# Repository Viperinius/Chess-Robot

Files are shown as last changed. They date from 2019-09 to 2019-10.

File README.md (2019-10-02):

# Chess-Robot

## Structure Overview
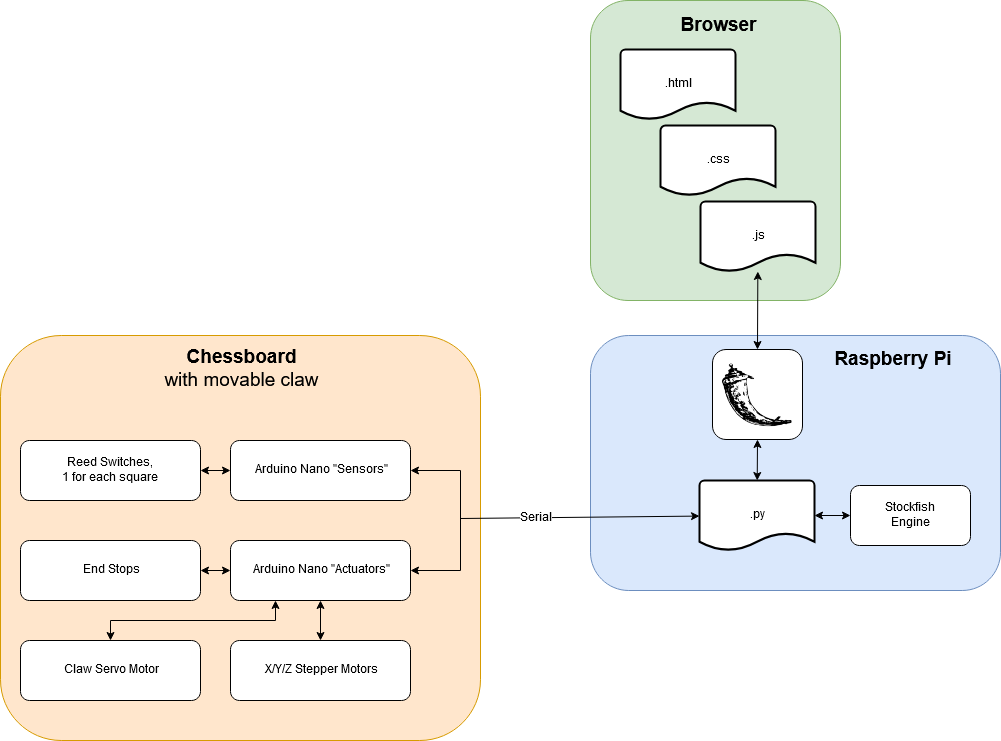
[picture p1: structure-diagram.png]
structOverviewImg


## Frame Design
Currently draft only:
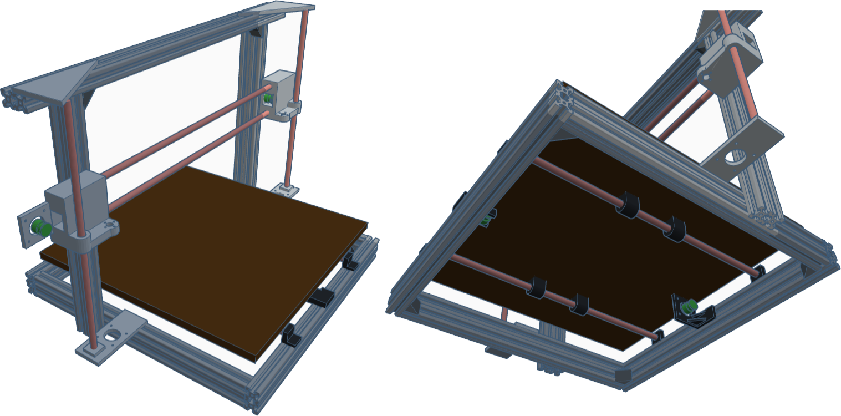
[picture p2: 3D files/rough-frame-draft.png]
frameDraftImg


## Current Schematic and PCB
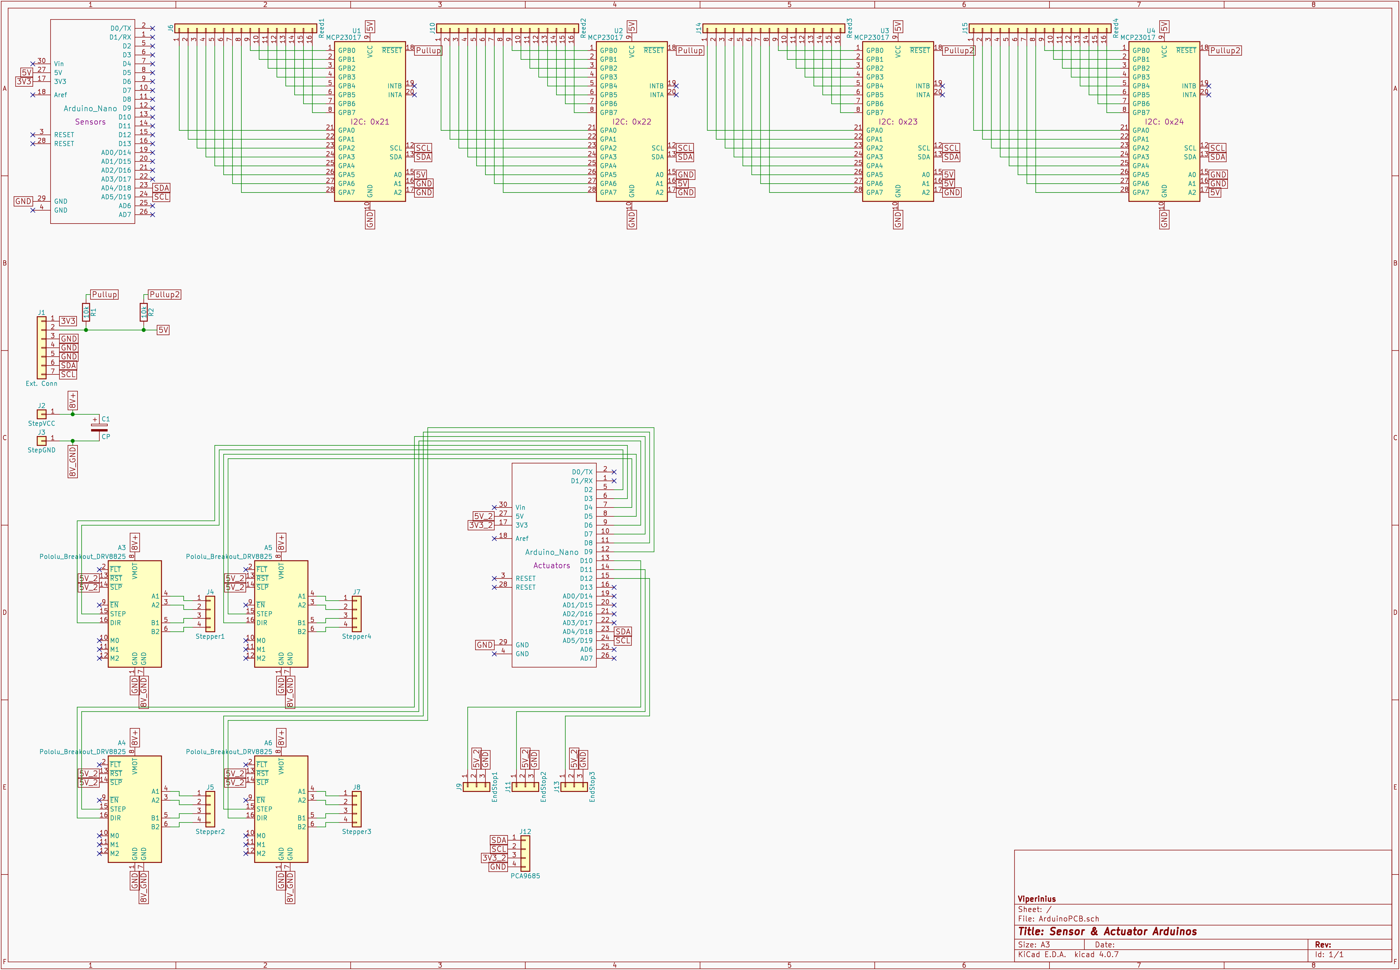
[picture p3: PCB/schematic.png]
schematicImg


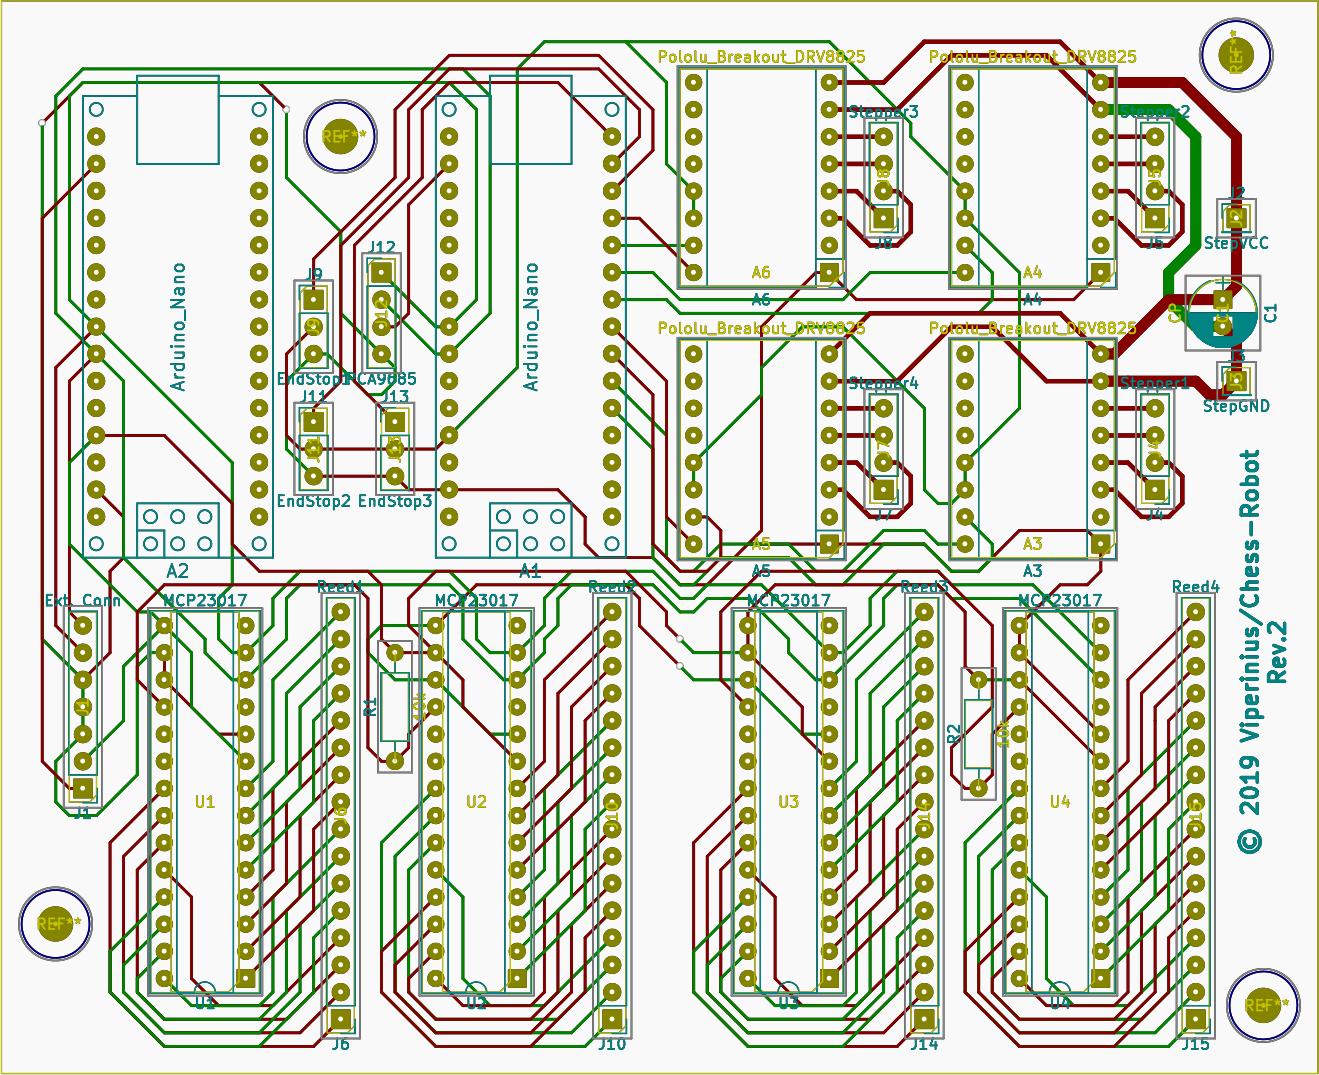
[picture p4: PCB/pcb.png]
pcbImg


## Used libraries / Libraries needed to run
- Used for programming web page, Stockfish & Arduino bridge:
    + [Adafruit MCP23017 Library](https://github.com/adafruit/Adafruit-MCP23017-Arduino-Library)
    + [chess.js](https://github.com/jhlywa/chess.js)
    + [chessboardjs](https://github.com/oakmac/chessboardjs/)
    + [Stockfish](https://github.com/official-stockfish/Stockfish)
    + [stockfish Python package](https://github.com/zhelyabuzhsky/stockfish)
- Used for schematic / PCB layout (KiCad):
    + [arduino_nano](https://github.com/kiwichrish/kicad_ArduinoNano)

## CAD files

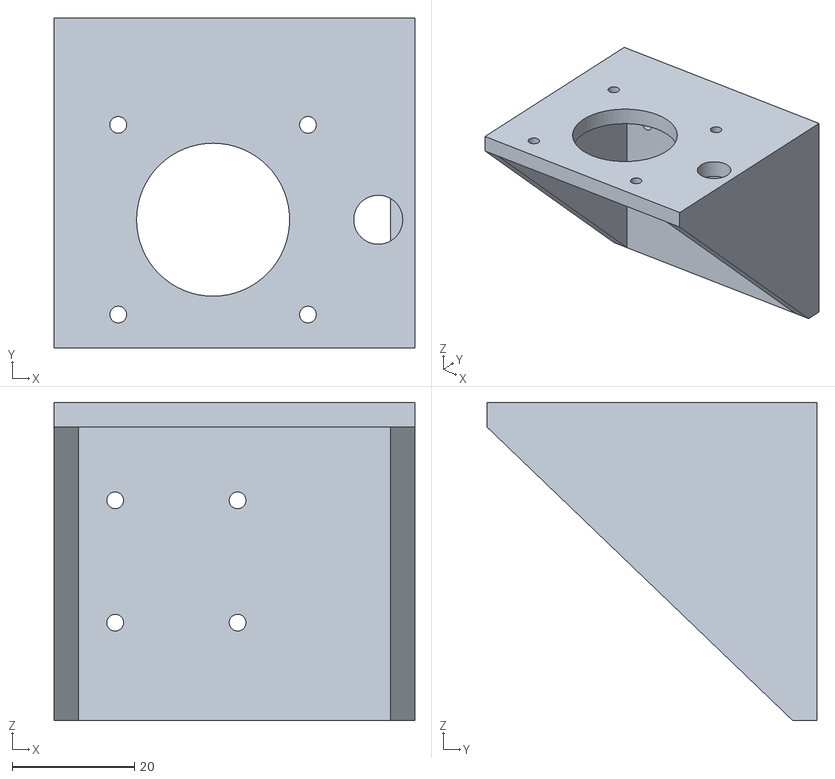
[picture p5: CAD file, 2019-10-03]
3D files/frame-bottom/z-stepper-holder-right.stl
59.0 x 54.0 x 52.0

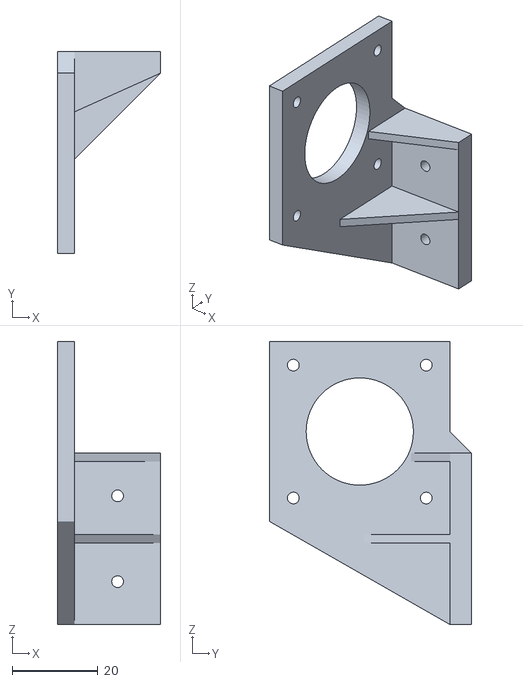
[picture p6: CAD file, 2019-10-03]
3D files/frame-bottom/y-stepper-holder.stl
24.0 x 47.0 x 66.0

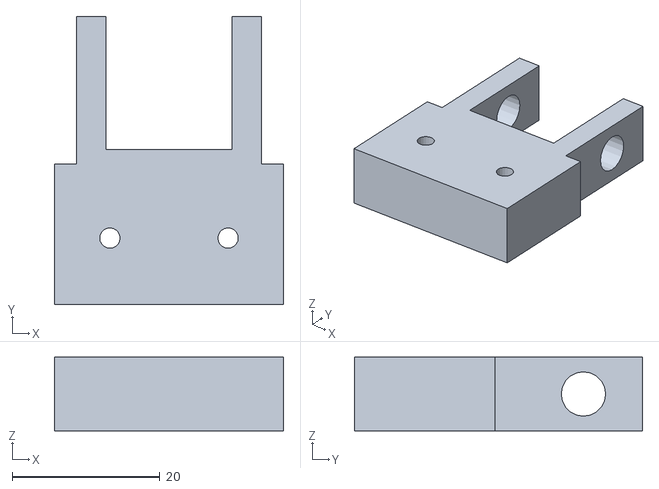
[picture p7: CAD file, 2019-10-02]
3D files/frame-bottom/belt-guide-holder.stl
31.0 x 39.0 x 10.0

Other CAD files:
3D files/frame-bottom/z-stepper-holder-left.stl

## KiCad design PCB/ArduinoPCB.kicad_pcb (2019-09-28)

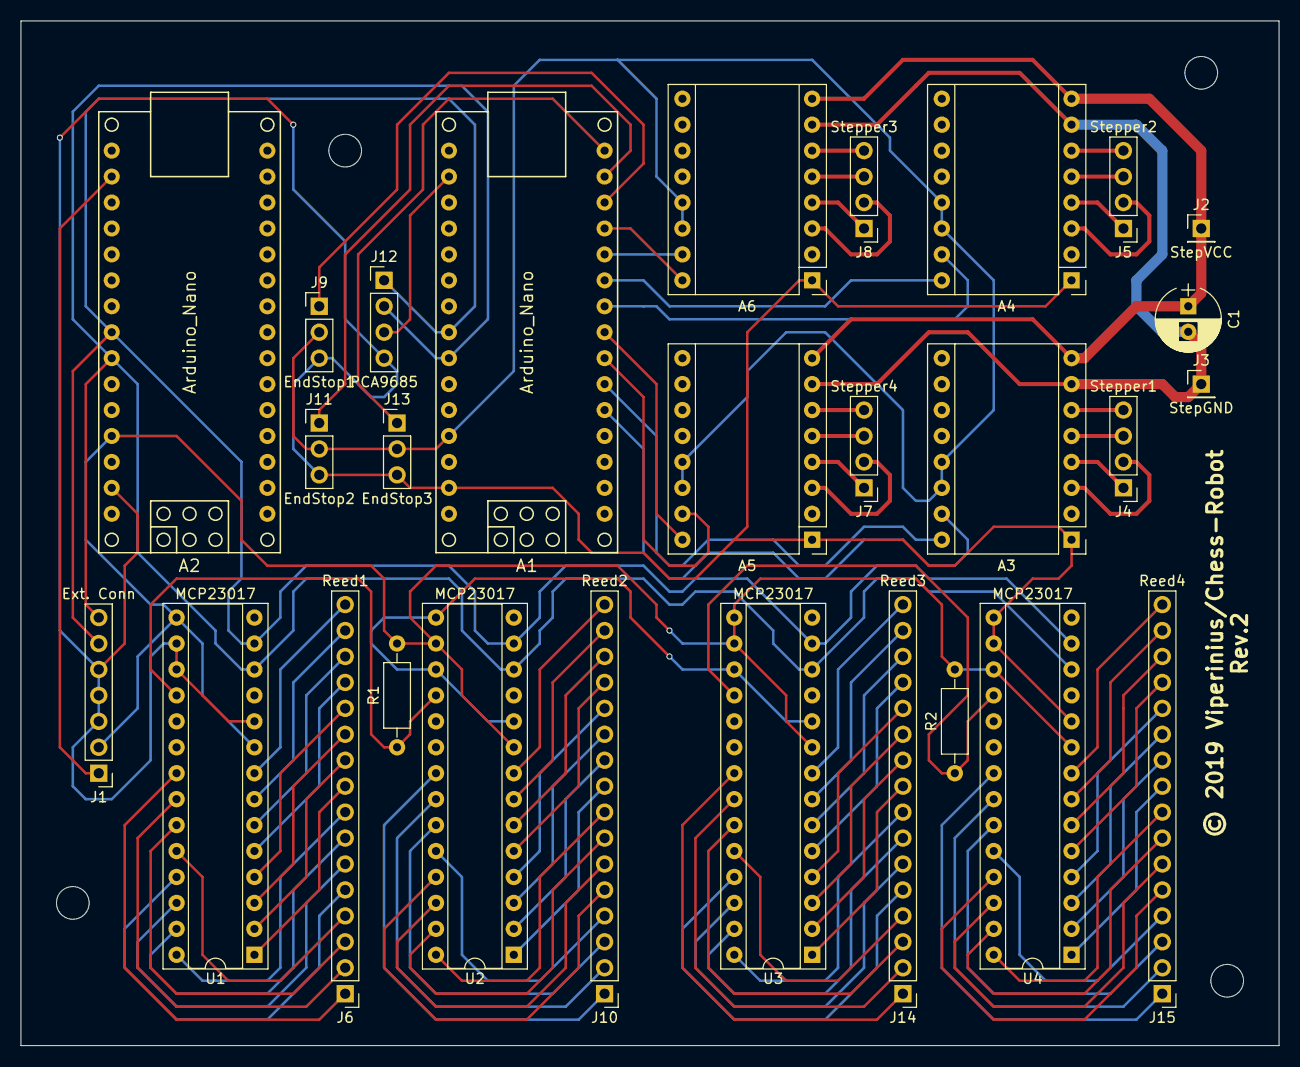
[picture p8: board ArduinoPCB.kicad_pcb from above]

Board: 2 copper layers, 123.2 x 100.3 mm, 28 parts (0 on the bottom side), 102 nets.

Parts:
A1, A2: Arduino_Nano; arduino_nano
A3, A4, A5, A6: Pololu_Breakout_DRV8825; Pololu_Breakout-16_15.2x20.3mm
C1: CP; CP_Radial_D6.3mm_P2.50mm
J1: Ext. Conn; Pin_Header_Straight_1x07_Pitch2.54mm
J2: StepVCC; Pin_Header_Straight_1x01_Pitch2.54mm
J3: StepGND; Pin_Header_Straight_1x01_Pitch2.54mm
J4: Stepper1; Pin_Header_Straight_1x04_Pitch2.54mm
J5: Stepper2; Pin_Header_Straight_1x04_Pitch2.54mm
J6: Reed1; Pin_Header_Straight_1x16_Pitch2.54mm
J7: Stepper4; Pin_Header_Straight_1x04_Pitch2.54mm
J8: Stepper3; Pin_Header_Straight_1x04_Pitch2.54mm
J9: EndStop1; Pin_Header_Straight_1x03_Pitch2.54mm
J10: Reed2; Pin_Header_Straight_1x16_Pitch2.54mm
J11: EndStop2; Pin_Header_Straight_1x03_Pitch2.54mm
J12: PCA9685; Pin_Header_Straight_1x04_Pitch2.54mm
J13: EndStop3; Pin_Header_Straight_1x03_Pitch2.54mm
J14: Reed3; Pin_Header_Straight_1x16_Pitch2.54mm
J15: Reed4; Pin_Header_Straight_1x16_Pitch2.54mm
R1, R2: 10k; R_Axial_DIN0207_L6.3mm_D2.5mm_P10.16mm_Horizontal
U1, U2, U3, U4: MCP23017; DIP-28_W7.62mm_Socket

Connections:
3V3: A2.17, J1.1
3V3_2: A1.17, J12.3
5V: A2.27, J1.2, R1.2, R2.2, U1.9, U1.15, U2.9, U2.16, U3.9, U3.15, U3.16, U4.9, U4.17
5V_2: A1.27, A3.13, A3.14, A4.13, A4.14, A5.13, A5.14, A6.13, A6.14, J9.2, J11.2, J13.2
8V+: A3.8, A4.8, A5.8, A6.8, C1.1, J2.1
8V_GND: A3.7, A4.7, A5.7, A6.7, C1.2, J3.1
GND: A1.29, A2.29, A3.1, A4.1, A5.1, A6.1, J1.3, J1.4, J1.5, J9.3, J11.3, J12.4, J13.3, U1.10, U1.16, U1.17, U2.10, U2.15, U2.17, U3.10, U3.17, U4.10, U4.15, U4.16
unnamed: A1.5, A3.15
unnamed: A1.6, A3.16
unnamed: A1.7, A5.15
unnamed: A1.8, A5.16
unnamed: A1.9, A4.15
unnamed: A1.10, A4.16
unnamed: A1.11, A6.15
unnamed: A1.12, A6.16
unnamed: A1.13, J9.1
unnamed: A1.14, J11.1
unnamed: A1.15, J13.1
unnamed: A3.3, J4.2
unnamed: A3.4, J4.1
unnamed: A3.5, J4.3
unnamed: A3.6, J4.4
unnamed: A4.3, J5.2
unnamed: A4.4, J5.1
unnamed: A4.5, J5.3
unnamed: A4.6, J5.4
unnamed: A5.3, J7.2
unnamed: A5.4, J7.1
unnamed: A5.5, J7.3
unnamed: A5.6, J7.4
unnamed: A6.3, J8.2
unnamed: A6.4, J8.1
unnamed: A6.5, J8.3
unnamed: A6.6, J8.4
unnamed: J6.1, U1.21
unnamed: J6.2, U1.22
unnamed: J6.3, U1.23
unnamed: J6.4, U1.24
unnamed: J6.5, U1.25
unnamed: J6.6, U1.26
unnamed: J6.7, U1.27
unnamed: J6.8, U1.28
unnamed: J6.9, U1.1
unnamed: J6.10, U1.2
unnamed: J6.11, U1.3
unnamed: J6.12, U1.4
unnamed: J6.13, U1.5
unnamed: J6.14, U1.6
unnamed: J6.15, U1.7
unnamed: J6.16, U1.8
unnamed: J10.1, U2.21
unnamed: J10.2, U2.22
unnamed: J10.3, U2.23
unnamed: J10.4, U2.24
unnamed: J10.5, U2.25
unnamed: J10.6, U2.26
unnamed: J10.7, U2.27
unnamed: J10.8, U2.28
unnamed: J10.9, U2.1
unnamed: J10.10, U2.2
unnamed: J10.11, U2.3
unnamed: J10.12, U2.4
unnamed: J10.13, U2.5
unnamed: J10.14, U2.6
unnamed: J10.15, U2.7
unnamed: J10.16, U2.8
unnamed: J14.1, U3.21
unnamed: J14.2, U3.22
unnamed: J14.3, U3.23
unnamed: J14.4, U3.24
unnamed: J14.5, U3.25
unnamed: J14.6, U3.26
unnamed: J14.7, U3.27
unnamed: J14.8, U3.28
unnamed: J14.9, U3.1
unnamed: J14.10, U3.2
unnamed: J14.11, U3.3
unnamed: J14.12, U3.4
unnamed: J14.13, U3.5
unnamed: J14.14, U3.6
unnamed: J14.15, U3.7
unnamed: J14.16, U3.8
unnamed: J15.1, U4.21
unnamed: J15.2, U4.22
unnamed: J15.3, U4.23
unnamed: J15.4, U4.24
unnamed: J15.5, U4.25
unnamed: J15.6, U4.26
unnamed: J15.7, U4.27
unnamed: J15.8, U4.28
unnamed: J15.9, U4.1
unnamed: J15.10, U4.2
unnamed: J15.11, U4.3
unnamed: J15.12, U4.4
unnamed: J15.13, U4.5
unnamed: J15.14, U4.6
unnamed: J15.15, U4.7
unnamed: J15.16, U4.8
Pullup: R1.1, U1.18, U2.18
Pullup2: R2.1, U3.18, U4.18
SCL: A1.24, A2.24, J1.7, J12.2, U1.12, U2.12, U3.12, U4.12
SDA: A1.23, A2.23, J1.6, J12.1, U1.13, U2.13, U3.13, U4.13

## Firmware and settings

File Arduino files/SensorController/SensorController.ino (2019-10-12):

//==============================================================================
/// @file SensorController.ino
///
/// @brief Implements reed switch reading and move recognition
///
/// @version 1.2
///
/// @author Viperinius
///
/// @date 11.10.2019
//==============================================================================


/* Board:
    x  x  x  x  x  x  x  x    8    |            MCP78   Pins 8-15
    x  x  x  x  x  x  x  x    7    | black      MCP78   Pins 0-7
    x  x  x  x  x  x  x  x    6                 MCP56   Pins 8-15
    x  x  x  x  x  x  x  x    5                 MCP56   Pins 0-7
    x  x  x  x  x  x  x  x    4                 MCP34   Pins 8-15
    x  x  x  x  x  x  x  x    3                 MCP34   Pins 0-7
    x  x  x  x  x  x  x  x    2    | white      MCP12   Pins 8-15
    x  x  x  x  x  x  x  x    1    |            MCP12   Pins 0-7
    a  b  c  d  e  f  g  h                              Pin number increased from left/a to right/h
*/




//------------------------------------------------------------------------------
//                                    Includes
//------------------------------------------------------------------------------

#include <Wire.h>
#include <Adafruit_MCP23017.h>



//------------------------------------------------------------------------------
//                                    Defines
//------------------------------------------------------------------------------
#define DEBUG 1                                 ///< enables or disables certain code for debugging


#define BAUD_RATE 9600                          ///< set the baud raute used to communicate
#define SLEEP_MS 1500                           ///< set how much delay is in between a loop cycle
#define SLEEP_MS_NEW_GAME 90000                 ///< set how much time a player has between requesting a new game and the actual game start
#define REQUEST_POS 10                          ///< message code for a current positions request
#define REQUEST_NEW_GAME 20                     ///< message code for a new game requested
#define MODE_BOARD 1                            ///< code for play mode board only
#define MODE_WEB 2                              ///< code for play mode web

#define REQ_POS_MSG "<SEND_CURR_POS>"           ///< message to expect to recognise a current positions request
#define REQ_NEW_GAME_MSG "<RESET_GAME>"         ///< message to expect to recognise a new game request
#define COMM_READY_MSG "<SENSORS_COMM_READY>"   ///< message to send that communication is ready
#define MODE_MSG_BOARD "<MODE_BOARD>"           ///< message to expect to set play mode to board only
#define MODE_MSG_WEB "<MODE_WEB>"               ///< message to expect to set play mode to web

//------------------------------------------------------------------------------
//                                    Variables
//------------------------------------------------------------------------------

// I/O extenders, each connected to two rows of the board
Adafruit_MCP23017 mcpRow12;        ///< I/O extender for first and second row
Adafruit_MCP23017 mcpRow34;        ///< I/O extender for third and fourth row
Adafruit_MCP23017 mcpRow56;        ///< I/O extender for fifth and sixth row
Adafruit_MCP23017 mcpRow78;        ///< I/O extender for seventh and eighth row

// keep starting positions at hand for easy copying
/// backup of the starting positions
const int iStartPos[8][8] = {
    { 1,1,1,1,1,1,1,1 },
    { 1,1,1,1,1,1,1,1 },
    { 0,0,0,0,0,0,0,0 },
    { 0,0,0,0,0,0,0,0 },
    { 0,0,0,0,0,0,0,0 },
    { 0,0,0,0,0,0,0,0 },
    { 1,1,1,1,1,1,1,1 },
    { 1,1,1,1,1,1,1,1 }
};

// arrays to save read positions
int iPrevPos[8][8];     ///< array to store the previous positions
int iCurrPos[8][8];     ///< array to store the current positions

// status if / what serial message received
int iSerialMsg;         ///< contains the message read from serial

// contains detected move with board columns as numbers instead of letters
int iMove;              ///< contains unformatted detected move

// status if comparePositions has detected a move
bool bMoveDetected;     ///< indicates if comparePostions detected a move

// "play mode", either board only (MODE_BOARD) or on web page (MODE_WEB)
uint8_t uiMode;         ///< contains current play mode

//------------------------------------------------------------------------------
//                                    Functions
//------------------------------------------------------------------------------

//==============================================================================
/// @brief Resets the position arrays
///
/// @details
/// Fill the board position arrays with initial values
//==============================================================================
void resetBoardArr() {
    for (int i = 0; i < 8; i++)
    {
        for (int j = 0; j < 8; j++)
        {
            iCurrPos[i][j] = iStartPos[i][j];
            iPrevPos[i][j] = iStartPos[i][j];
        }
    }
}

//==============================================================================
/// @brief Copy current position array to previous position array
///
/// @details
/// Copies all current positions from their array to the previous one.
//==============================================================================
void copyCurrToPrevPos() {
    for (int i = 0; i < 8; i++)
    {
        for (int j = 0; j < 8; j++)
        {
            iPrevPos[i][j] = iCurrPos[i][j];
        }
    }
}

//==============================================================================
/// @brief Generate unformatted move
///
/// @details
/// Generates the variable containing the unformatted move (move with numbers only)
///
/// @param [in] iSrcI    origin row
/// @param [in] iSrcJ    origin column
/// @param [in] iDestI    destination row
/// @param [in] iDestJ    destination column
///
/// @return The unformatted move as int
//==============================================================================
int generateMoveVar(int iSrcI, int iSrcJ, int iDestI, int iDestJ) {
    //returns move with columns as numbers instead of letters
    return iSrcJ * 1000 + iSrcI * 100 + iDestJ * 10 + iDestI;
}

//==============================================================================
/// @brief Check if move happened
///
/// @details
/// Compares position arrays to check if a piece changed position
///
/// @return -1 if no move detected, unformatted move otherwise
//==============================================================================
int comparePositions() {
    int iSrcI = -1;
    int iSrcJ = -1;
    int iDestI = -1;
    int iDestJ = -1;

    for (int i = 0; i < 8; i++)
    {
        for (int j = 0; j < 8; j++)
        {
            if (iCurrPos[i][j] != iPrevPos[i][j]) {
                if (iCurrPos[i][j] == 1) {
                    //piece appeared

                    iDestI = i;
                    iDestJ = j;
                }
                else if (iCurrPos[i][j] == 0) {
                    //piece disappeared

                    iSrcI = i;
                    iSrcJ = j;
                }
            }
        }
    }

    //return the move if all parts valid, else -1 (no actual move seen)
    if (iSrcI >= 0 && iSrcJ >= 0 && iDestI >= 0 && iDestJ >= 0) {
        bMoveDetected = true;
        return generateMoveVar(iSrcI + 1, iSrcJ + 1, iDestI + 1, iDestJ + 1);
    }
    bMoveDetected = false;
    return -1;
}

//==============================================================================
/// @brief Initialise the MCP23017
///
/// @details
/// Initialises the four port extenders
//==============================================================================
void initMCP() {
    mcpRow12.begin(1);    //I2C: 0x21
    mcpRow34.begin(2);    //I2C: 0x22
    mcpRow56.begin(3);    //I2C: 0x23
    mcpRow78.begin(4);    //I2C: 0x24

    for (int i = 0; i < 16; i++)
    {
        mcpRow12.pinMode(i, INPUT);
        mcpRow34.pinMode(i, INPUT);
        mcpRow56.pinMode(i, INPUT);
        mcpRow78.pinMode(i, INPUT);

        mcpRow12.pullUp(i, HIGH);
        mcpRow34.pullUp(i, HIGH);
        mcpRow56.pullUp(i, HIGH);
        mcpRow78.pullUp(i, HIGH);
    }
}

//==============================================================================
/// @brief Read all reed switches
///
/// @details
/// Reads all inputs of the I/O extenders and fills position arrays
//==============================================================================
void readSensors() {
    int iTemp = 0;
    for (int i = 0; i < 8; i++)
    {
        for (int j = 0; j < 8; j++)
        {
            switch (i)
            {
            case 0:
                iTemp = mcpRow12.digitalRead(j);
                break;
            case 1:
                iTemp = mcpRow12.digitalRead(j + 8);
                break;
            case 2:
                iTemp = mcpRow34.digitalRead(j);
                break;
            case 3:
                iTemp = mcpRow34.digitalRead(j + 8);
                break;
            case 4:
                iTemp = mcpRow56.digitalRead(j);
                break;
            case 5:
                iTemp = mcpRow56.digitalRead(j + 8);
                break;
            case 6:
                iTemp = mcpRow78.digitalRead(j);
                break;
            case 7:
                iTemp = mcpRow78.digitalRead(j + 8);
                break;
            default:
                break;
            }

            // invert actual value because of pullup in mcp / reed switches gnd
            if (iTemp == 1)
            {
                iCurrPos[i][j] = 0;
            }
            else
            {
                iCurrPos[i][j] = 1;
            }
        }
    }    
}

//==============================================================================
/// @brief Read serial
///
/// @details
/// Checks if new serial message available and reads it
///
/// @return -1 if no or incompatible message received, otherwise message codes
//==============================================================================
int readSerial() {
    char cRead;
    String sContent = "";

    if (!Serial.available()) {
        return -1;
    }
    while (Serial.available()) {
        cRead = Serial.read();
        sContent.concat(cRead);
    }
    
    if (sContent == REQ_POS_MSG) {
        return REQUEST_POS;
    }
    else if (sContent == REQ_NEW_GAME_MSG) {
        return REQUEST_NEW_GAME;
    }
    else if (sContent == MODE_MSG_BOARD) {
        return MODE_BOARD;
    }
    else if (sContent == MODE_MSG_WEB) {
        return MODE_WEB;
    }
    else {
        return -1;
    }
}


//------------------------------------------------------------------------------
//                                    Main Functions
//------------------------------------------------------------------------------

//==============================================================================
/// @brief Prepare loop
///
/// @details
/// Initialises needed things
//==============================================================================
void setup() {
    Serial.begin(BAUD_RATE);
    pinMode(LED_BUILTIN, OUTPUT);
    Serial.println(COMM_READY_MSG);

    initMCP();

    resetBoardArr();

    iSerialMsg = 0;
    bMoveDetected = false;
    //set default mode to board only
    uiMode = MODE_BOARD;

#ifdef DEBUG
    Serial.println("SETUP DONE");
#endif // DEBUG

}

//==============================================================================
/// @brief Main loop
///
/// @details
/// Main loop
//==============================================================================
void loop() {
    //check if server sent a request
    iSerialMsg = readSerial();
    if (iSerialMsg > 0) {
        //valid message received
        if (iSerialMsg == REQUEST_POS) {
            iMove = comparePositions();

            if (bMoveDetected) {
                //send latest move
                Serial.println(iMove);
            }
        }
        else if (iSerialMsg == REQUEST_NEW_GAME) {
            resetBoardArr();

            //pause loop to allow players to reposition the pieces back
            delay(SLEEP_MS_NEW_GAME);
        }
        else if (iSerialMsg == MODE_BOARD || iSerialMsg == MODE_WEB) {
            //change mode to received value
            uiMode = iSerialMsg;
        }
    }
    else
    {
        copyCurrToPrevPos();

        readSensors();

        // testing stuff
        Serial.println("-----------");
        //print curr array
        for (int i = 0; i < 8; i++)
        {
            for (int j = 0; j < 8; j++)
            {
                Serial.print(iCurrPos[i][j]);
                Serial.print(" ");
                if (j == 7) {
                    Serial.print("\r\n");
                }
            }
        }
        digitalWrite(LED_BUILTIN, iCurrPos[4][7]);

        // end testing stuff

        if (uiMode == MODE_BOARD) {
            iMove = comparePositions();

            if (bMoveDetected) {
                //send latest move
                Serial.println(iMove);
            }
        }


        delay(SLEEP_MS);
    }

}

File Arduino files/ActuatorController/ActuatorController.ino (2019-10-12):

//==============================================================================
/// @file ActuatorController.ino
///
/// @brief Implements movement control
///
/// @version 1.1
///
/// @author Viperinius
///
/// @date 11.10.2019
//==============================================================================


//------------------------------------------------------------------------------
//                                    Includes
//------------------------------------------------------------------------------

#include <avr/interrupt.h>


//------------------------------------------------------------------------------
//                                    Defines
//------------------------------------------------------------------------------

#define BAUD_RATE 9600                          ///< set the baud raute used to communicate
#define SLEEP_MS 500                            ///< set how much delay is in between loop cycles
#define COMM_READY_MSG "<SENSORS_COMM_READY>"   ///< message to send that communication is ready

#define PIN_END_STOP_1 10                       ///< pin of the x end stop
#define PIN_END_STOP_2 11                       ///< pin of the y end stop
#define PIN_END_STOP_3 12                       ///< pin of the z end stop


//------------------------------------------------------------------------------
//                                    Variables
//------------------------------------------------------------------------------

volatile uint8_t uiIsrValue;                    ///< holds value if or which end stop triggered an interrupt



//------------------------------------------------------------------------------
//                                    Functions
//------------------------------------------------------------------------------

//==============================================================================
/// @brief Initialise the end stop pins
///
/// @details
/// Set pin mode
//==============================================================================
void initEndStops() {
    pinMode(PIN_END_STOP_1, INPUT);
    pinMode(PIN_END_STOP_2, INPUT);
    pinMode(PIN_END_STOP_3, INPUT);
}

//==============================================================================
/// @brief Initialise the PCI
///
/// @details
/// Enables pin change interrupts for the end stops
//==============================================================================
void initPCI() {

    uiIsrValue = 0;

    cli();
    // enable port B PCI
    PCICR |= 0b00000001;
    // enable interrupt on D10, D11 and D12
    PCMSK0 |= 0b00011100;

    sei();
}




//------------------------------------------------------------------------------
//                                    Main Functions
//------------------------------------------------------------------------------

//==============================================================================
/// @brief Prepare loop
///
/// @details
/// Initialises needed things
//==============================================================================
void setup() {
    Serial.begin(BAUD_RATE);
    pinMode(LED_BUILTIN, OUTPUT);
    Serial.println(COMM_READY_MSG);

    initPCI();
    initEndStops();
    
}

//==============================================================================
/// @brief Main loop
///
/// @details
/// Main loop
//==============================================================================
void loop() {
    





    delayMicroseconds(SLEEP_MS);
}



ISR(PCINT0_vect) {
    // sets bits according to end stop states:
    // 0 -> no end stop active
    // 1 -> end stop 1 triggered
    // 2 -> end stop 2 triggered
    // 3 -> end stop 1 and 2 active
    // 4 -> end stop 3 triggered
    // 5 -> end stop 1 and 3 active
    // 6 -> end stop 2 and 3 triggered
    // 7 -> all end stops active
    uiIsrValue = !digitalRead(PIN_END_STOP_1) | (!digitalRead(PIN_END_STOP_2) << 1) | (!digitalRead(PIN_END_STOP_3) << 2);
}

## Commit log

2019-08-20 added basic board functions to the webpage
2019-08-25 added first version of Arduino Python communication (Python side)
2019-08-27 added first functions for sensor reading and init functions
2019-08-30 filled sensor arduino loop with first draft, added functions for serial comms
2019-08-31 testing with MCPs, added first PCB try
    [ArduinoPCB.kicad_pcb, ArduinoPCB.sch, MCP23017PCB.kicad_pcb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]
2019-09-24 added first complete schematic and PCB version
    [ArduinoPCB.kicad_pcb, ArduinoPCB.sch]
2019-09-25 Rev2 of PCB
    [ArduinoPCB.kicad_pcb]
2019-09-28 minimal PCB changes to be able to manufacture it, added image
    [ArduinoPCB.kicad_pcb, ArduinoPCB.sch, MCP23017PCB.kicad_pcb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]
2019-10-02 added first frame design draft and belt-guide-holder
    [belt-guide-holder.stl]
2019-10-03 adding more stl files
    [y-stepper-holder.stl, z-stepper-holder-left.stl, z-stepper-holder-right.stl]
2019-10-12 added arduino code documentation, added end stop implementation, fixed readSerial
    [ActuatorController.ino, SensorController.ino]
2019-10-12 fixed Arduino indenting

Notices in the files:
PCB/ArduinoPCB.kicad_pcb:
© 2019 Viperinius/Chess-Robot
